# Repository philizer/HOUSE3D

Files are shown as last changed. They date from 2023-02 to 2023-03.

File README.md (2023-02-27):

# HOUSE3D
Tutorial and files for operating HOUSE3D printer

# Safety rules
For SAFETY reasons, always keep an eye on the printer and do not use it alone (min 2 operators).
Do not go inside the printer when it’s powered 
If any problem occurs, press the emergency switch immediately.

## I - Switch on the printer
Check the cables connections and switch on 

## II - Connexion to the router and to the rasp
Connect to the wifi : “router”, pwd: “maisons3D”
In the terminal of your laptop: “ifconfig”: to find your ip
“nmap-sP 192.168.0.0/24”: see the different objects connected to the network, and find the ip of the rasp, the rasp’s IP may change.

## III - In the terminal windows/ubuntu - modify the printer's parameters
Write the ip of the Rasp “ssh pi@192.168.0.___”, id: “pi”, pwd: “printer”, you are now in pi@octopi
To get into the configuration file: “nano printer.cfg”
[printer.cfg]: the parts of the file that can be modified, as the rotation distance, the microsteps (need to be the same values as the drivers ones), the position max (the axis does not move beyond this value), …
If there have been any changes: crtl O - enter - ctrl X - enter

## IV - Debugs - in the terminal
“sudo service klipper status”, to get the status of klipper
“sudo service klipper stop”, to stop klipper
“sudo service klipper start”, to start klipper
“tail -f /tmp/klippy.log”, to get klipper log
“tail -f /tmp/printer”, to view the output of the printer

## V - Launch a print (CAO, mesh, slicer, gcode, OctoPrint …)

OctoPrint:

To access OctoPrint: enter the IP address of the rasp on your browser to go on the local network: “https://192.168.0.___”, id: “pi”, pwd: “printer0*”
Before each demand, it is necessary to go back to the origin, using the “house” button, or the command “G28”, in the terminal. To have only a specific axis go to the origin use the command “G28 X0” (for the x-axis) 
If any modifications have been done in the configuration’s files, write “FIRMWARE_RESTART” in the Octoprint terminal to take them into account.
If there is any error with the firmware, reconnect, and then write “FIRMWARE_RESTART” in the terminal
To print an object:
Design a part on a CAO software (Solidworks, Fusion, …) and export it as .STL file
Slice the design on PrusaSlicer using the slice profile attached
Export the .gcode and upload it on OctoPrint
Check the cables and connections
Check the belts’ tension
Home Z axis, press switch manually before hitting the ground
Launch Gcode (the printer will only home the X and Y axis when using the provided profile)

## VI - Shutdown the system
When finish using all the system, write “shutdown-now” in the terminal (in pi@octop) before switching the power off, to avoid damaging the Raspberry Pi

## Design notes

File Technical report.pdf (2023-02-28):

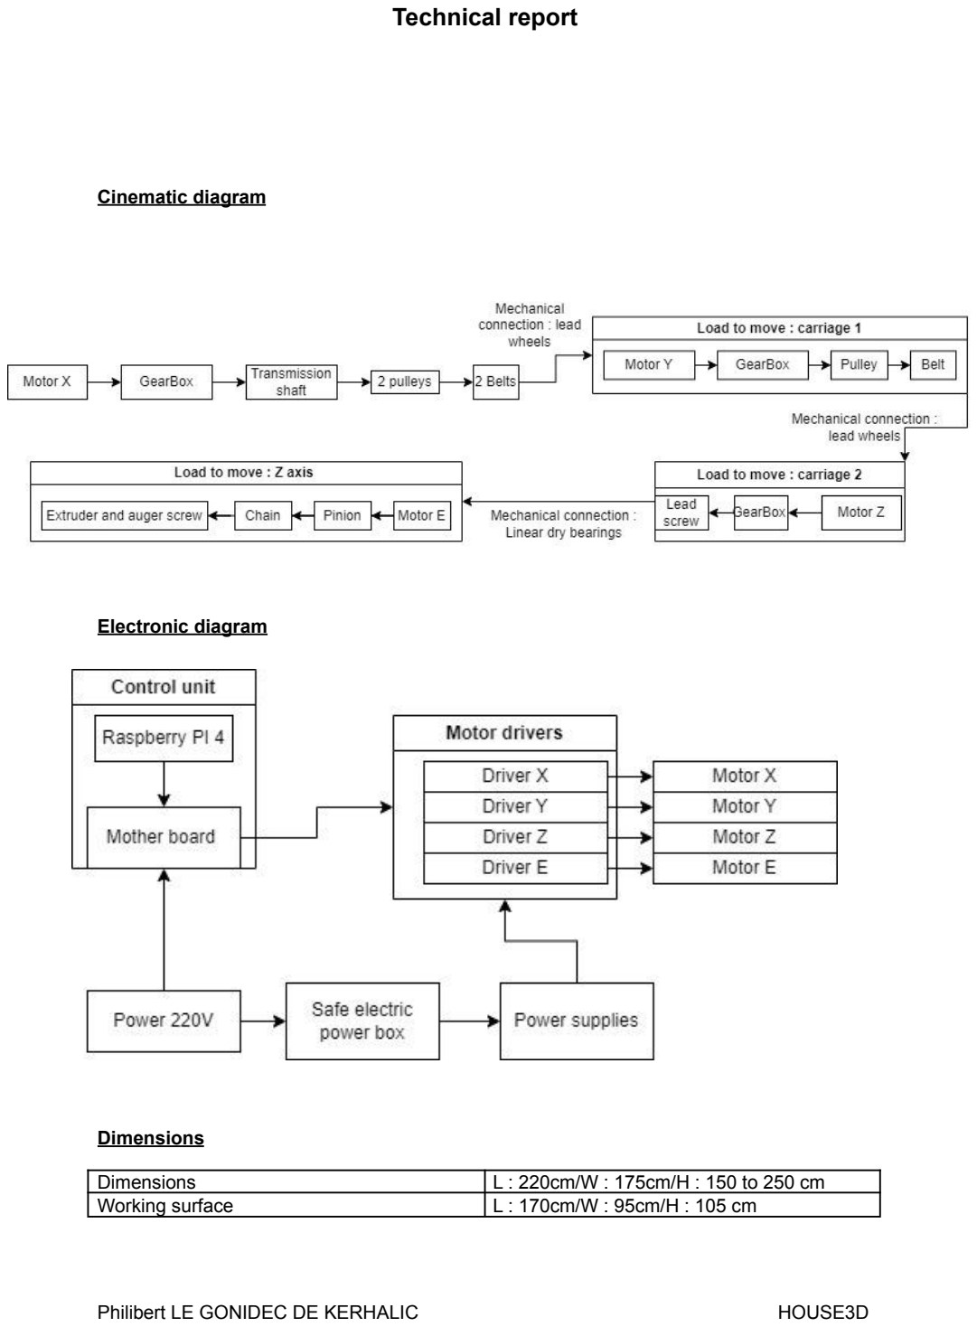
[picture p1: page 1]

### Technical report

Cinematic diagram

Electronic diagram

Dimensions

Dimensions | L : 220cm/W : 175cm/H : 150 to 250 cm
Working surface | L : 170cm/W : 95cm/H : 105 cm
Philibert LE GONIDEC DE KERHALIC | HOUSE3D

### Technical report

Main components

X and Y
6 pulleys AT5 20teeths
2x3m belts
1x 1.5m belt

Z
Lead screw: 1m50, 2mm thread 4xIGUS dry bearings

Trusses frame
4 Naxpro-Truss FD 24 Embase plate 4 Naxpro-Truss FD 24 Boxcorner
6 Naxpro-Truss FD 24 Length 125 cm 2 Naxpro-Truss FD 24 Length 175 cm 1 Naxpro-Truss FD 22 Length 150 cm 2 Naxpro-Truss FD 22 Longueur 100 cm

Motors
3 Nema 34 12Nm (X, Y, E)
1 Nema 23 3Nm (Z)
2 Nema 34 Planetary GearBoxes (1:20) 1 Nema 23 Planetary GearBox (1:20)

Drivers
1 DM542T (Z)
3 CL86T (X, Y, E)

Power Supplies
3 x 60V DC 5.9A output (X, Y, E) 1 x 24V DC 4.5A output (Z)

Control
1 Raspberry Pi 4 B
1 Skr V1.4 Turbo

Firmware
Klipper 0.11.0

Monitoring & control software OctoPi 0.18.0

Philibert LE GONIDEC DE KERHALIC | HOUSE3D

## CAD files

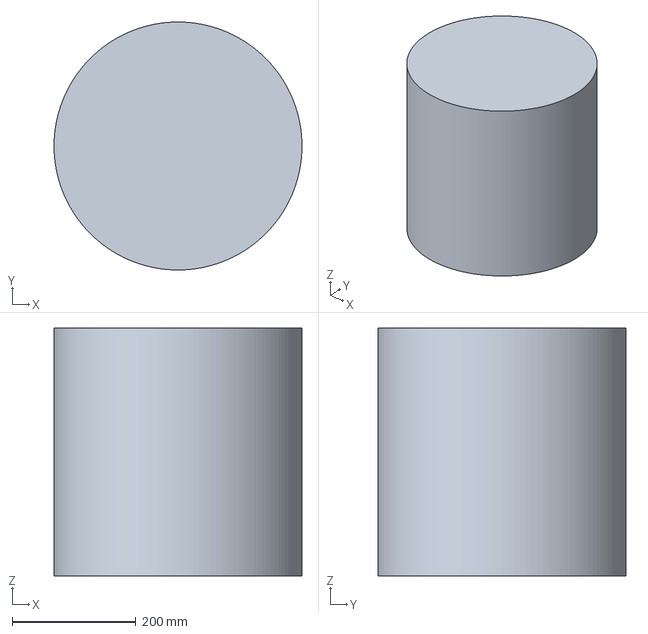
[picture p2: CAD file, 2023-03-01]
PrusaSlicer_HOUSE3D_Profile.3mf
400.0 x 399.9 x 400.0 mm

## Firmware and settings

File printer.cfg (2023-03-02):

[stepper_x]
step_pin: P2.2
dir_pin: P2.6
enable_pin: !P2.1
microsteps: 32
rotation_distance: 5
endstop_pin: !P1.29
position_endstop: 0
position_max : 1500
homing_speed: 50
homing_retract_dist: 50

[stepper_y]
step_pin: P0.19
dir_pin: P0.20
enable_pin: !P2.8
microsteps: 32
rotation_distance: 4.7
endstop_pin: !P1.28
position_endstop: 0
position_max : 500
homing_speed: 30
homing_retract_dist: 50


[stepper_z]
homing_retract_dist: 5
step_pin: P0.22
dir_pin: !P2.11
enable_pin: !P0.21
microsteps: 4
rotation_distance: 0.1
endstop_pin: !P1.27
position_endstop: 0.0
position_max: 600
homing_speed : 1

[extruder]
max_extrude_cross_section: 100000000
min_extrude_temp: -200

step_pin: P2.13
dir_pin: !P0.11
enable_pin: !P2.12
microsteps: 8
rotation_distance: 33.5
nozzle_diameter: 20
filament_diameter: 40
heater_pin: P2.7
sensor_type: EPCOS 100K B57560G104F
sensor_pin: P0.24
control: pid
pid_Kp: 22.2
pid_Ki: 1.08
pid_Kd: 114
min_temp: -200
max_temp: 260

max_extrude_only_distance: 9999999


[mcu]
serial: /dev/serial/by-id/usb-Klipper_lpc1769_1FD0FF0E871C4AAFCF3C7C5DC72000F5-if00

[printer]
kinematics: cartesian
max_velocity: 50
max_accel: 10
max_z_velocity: 1

max_z_accel: 1





[board_pins]
aliases:
    # EXP1 header
    EXP1_1=P1.30, EXP1_3=P1.18, EXP1_5=P1.20, EXP1_7=P1.22, EXP1_9=<GND>,
    EXP1_2=P0.28, EXP1_4=P1.19, EXP1_6=P1.21, EXP1_8=P1.23, EXP1_10=<5V>,
    # EXP2 header
    EXP2_1=P0.17, EXP2_3=P3.26, EXP2_5=P3.25, EXP2_7=P1.31, EXP2_9=<GND>,
    EXP2_2=P0.15, EXP2_4=P0.16, EXP2_6=P0.18, EXP2_8=<RST>, EXP2_10=<NC>
    # Pins EXP2_1, EXP2_6, EXP2_2 are also MISO, MOSI, SCK of bus "ssp0"

# See the sample-lcd.cfg file for definitions of common LCD displays.

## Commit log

2023-02-28 Technical report: schematics and main components
2023-03-01 Profile to print cool stuff
    For Prusa Slicer, adapt it to your needs.
    [PrusaSlicer_HOUSE3D_Profile.3mf]
2023-03-02 Printer's configuration file
    [printer.cfg]
